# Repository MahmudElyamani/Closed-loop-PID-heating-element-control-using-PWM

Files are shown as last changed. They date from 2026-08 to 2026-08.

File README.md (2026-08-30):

# Closed-Loop PID Polyimide Heater Controller

A compact 72×42 mm PCB that drives a polyimide (Kapton) film heater with closed-loop PID temperature control, selectable between three preset temperature stages via a single push button.

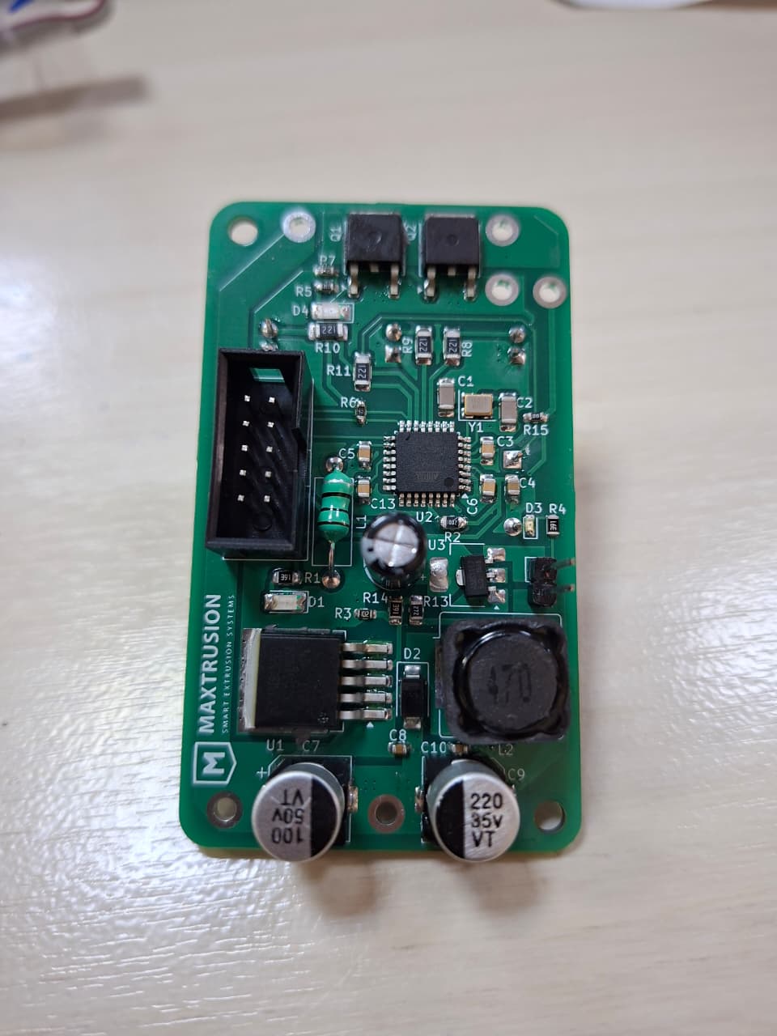
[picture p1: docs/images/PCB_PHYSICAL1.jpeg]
PCB Front

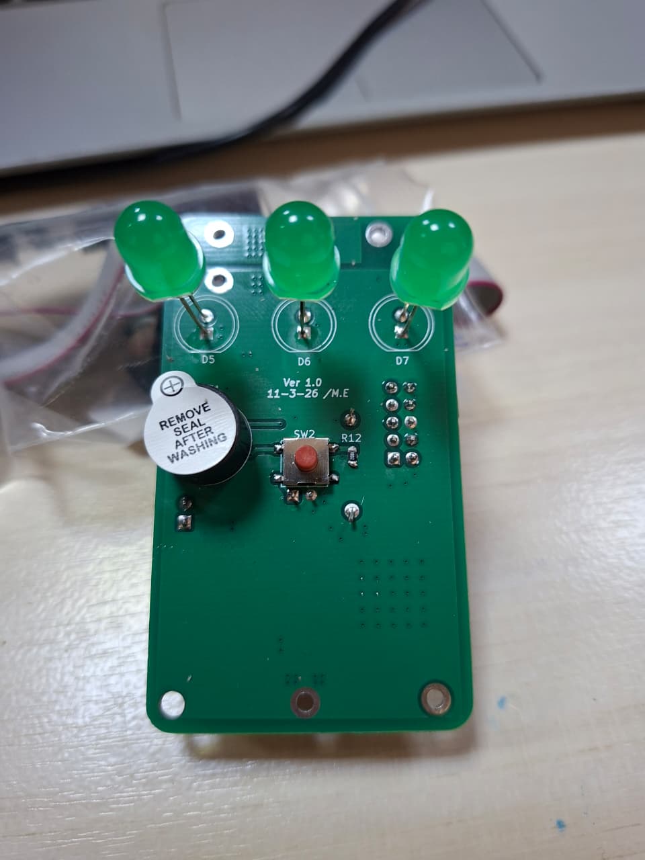
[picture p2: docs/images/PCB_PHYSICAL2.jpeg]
PCB Back


## Overview

This project was built to precisely and safely regulate the surface temperature of a polyimide heating element. Power switching is handled by a parallel dual-MOSFET stage driven by PWM from an ATmega328P, with temperature feedback provided by an NTC thermistor mounted on the heater. An onboard PID loop continuously adjusts duty cycle to track one of three user-selectable setpoints, with fault detection to shut everything down if the thermistor reading looks unsafe or the sensor is disconnected.

## Key Features

- **Closed-loop PID control** — thermistor feedback drives a PID loop that adjusts PWM duty cycle to hold the heater at the selected setpoint.
- **3 selectable temperature stages** (85 °C / 90 °C / 95 °C) — cycled with short button presses, each with its own status LED.
- **Press-and-hold start/stop** — holding the button for 2 seconds toggles the heater operation on or off, preventing accidental activation.
- **Fault protection** — the system continuously checks that the thermistor reading is within a safe, plausible range. If the reading looks unsafe (over-temperature or a disconnected/shorted sensor), the heater is disabled, a buzzer alert sounds, and the system latches into a fault state until conditions are safe again.
- **High-frequency PWM (~20 kHz)** — generated via direct Timer2 register configuration on the ATmega328P, above the audible range, for smoother MOSFET switching.
- **Averaged ADC sampling** — a rolling 500 ms window (100 samples at 5 ms spacing) smooths thermistor readings and rejects noise.
- **Audible feedback** — buzzer chirps on system start-up/ready and on operation stop.
- **Compact form factor** — entire control board fits on a 70×40 mm PCB.

## Hardware Summary

| Parameter | Value |
|---|---|
| Input power | 24 V, 5 A DC supply |
| Logic supply | Buck-regulated from 24 V rail down to 5 V for the ATmega328P |
| Power switching | 2× N-channel MOSFETs in parallel, PWM-gated |
| Microcontroller | ATmega328P (Arduino-compatible) |
| Temperature sensing | NTC thermistor (100 kΩ @ 25 °C, β ≈ 3950), voltage-divider with 100 kΩ series resistor |
| PWM frequency | ~20 kHz (Timer2, Fast PWM mode, prescaler 8, TOP = 99) |
| User interface | 1× push button, 3× status LEDs, 1× buzzer |
| Board size | 72 × 42 mm |

See [`hardware/README.md`](hardware/README.md) for schematic, PCB layout, and BOM details.

## How It Works

### Temperature sensing & safety check

The thermistor voltage is sampled every 5 ms and averaged over a rolling 500 ms window, then converted to °C using the Beta-parameter (simplified Steinhart-Hart) equation. Every loop iteration checks that:

- the computed temperature is below a danger threshold, **and**
- the raw ADC reading is below a value that would indicate a disconnected or shorted sensor.

If both checks pass, the system is marked safe and ready. If either fails, the system immediately disables the heater output, sounds the buzzer, and stays latched in a fault state until the reading recovers.

### Stage selection & control

Below is the operational flow, from power-up through fault handling:

```mermaid
flowchart TD
    A[Power On] --> B{Thermistor reading safe?}
    B -- No --> C[Fault state: heater off, buzzer alert]
    C --> B
    B -- Yes --> D[System Active / Ready]
    D --> E{Button held 2s?}
    E -- Yes --> F[Toggle Operation ON/OFF]
    F -->|OFF| D
    F -->|ON| G[Operation Active: PID control running]
    G --> H{Short button press?}
    H -- Yes --> I[Cycle Stage: 85C -> 90C -> 95C -> 85C]
    I --> G
    G --> B
```

Once operation is active, a PID loop (`Kp = 5.35, Ki = 0.5, Kd = 0.26`) computes a PWM duty cycle (0–80%) from the error between the current and target temperature, with integral anti-windup clamping. The corresponding status LED blinks while the heater is below its stage's threshold and turns solid once that threshold is reached.

See [`firmware/README.md`](firmware/README.md) for the full pin map and control-loop details.

## Repository Structure

```
heater-control-pcb/
├── README.md                 <- you are here
├── firmware/
│   ├── README.md             <- pin map, build/flash instructions, control logic
│   └── src/
│       └── main.cpp
├── hardware/
│   ├── README.md             <- PCB/schematic details, BOM
│   ├── schematic/            <- schematic PDF / source files
│   ├── pcb/                  <- PCB layout files, layer plots
│   ├── gerbers/              <- fabrication-ready Gerber/drill files
│   └── bom/                  <- bill of materials
└── docs/
    └── images/                <- board photos, renders, diagrams
```

## Getting Started

1. Clone the repository.
2. Fabricate the PCB using the files in [`hardware/gerbers`](hardware/gerbers).
3. Assemble per the BOM in [`hardware/bom`](hardware/bom).
4. Flash `firmware/src/main.cpp` to the ATmega328P — see [`firmware/README.md`](firmware/README.md) for details.
5. Connect a 24 V / 5 A supply and the polyimide heater + thermistor assembly.

## Gallery

| | | |
|---|---|---|
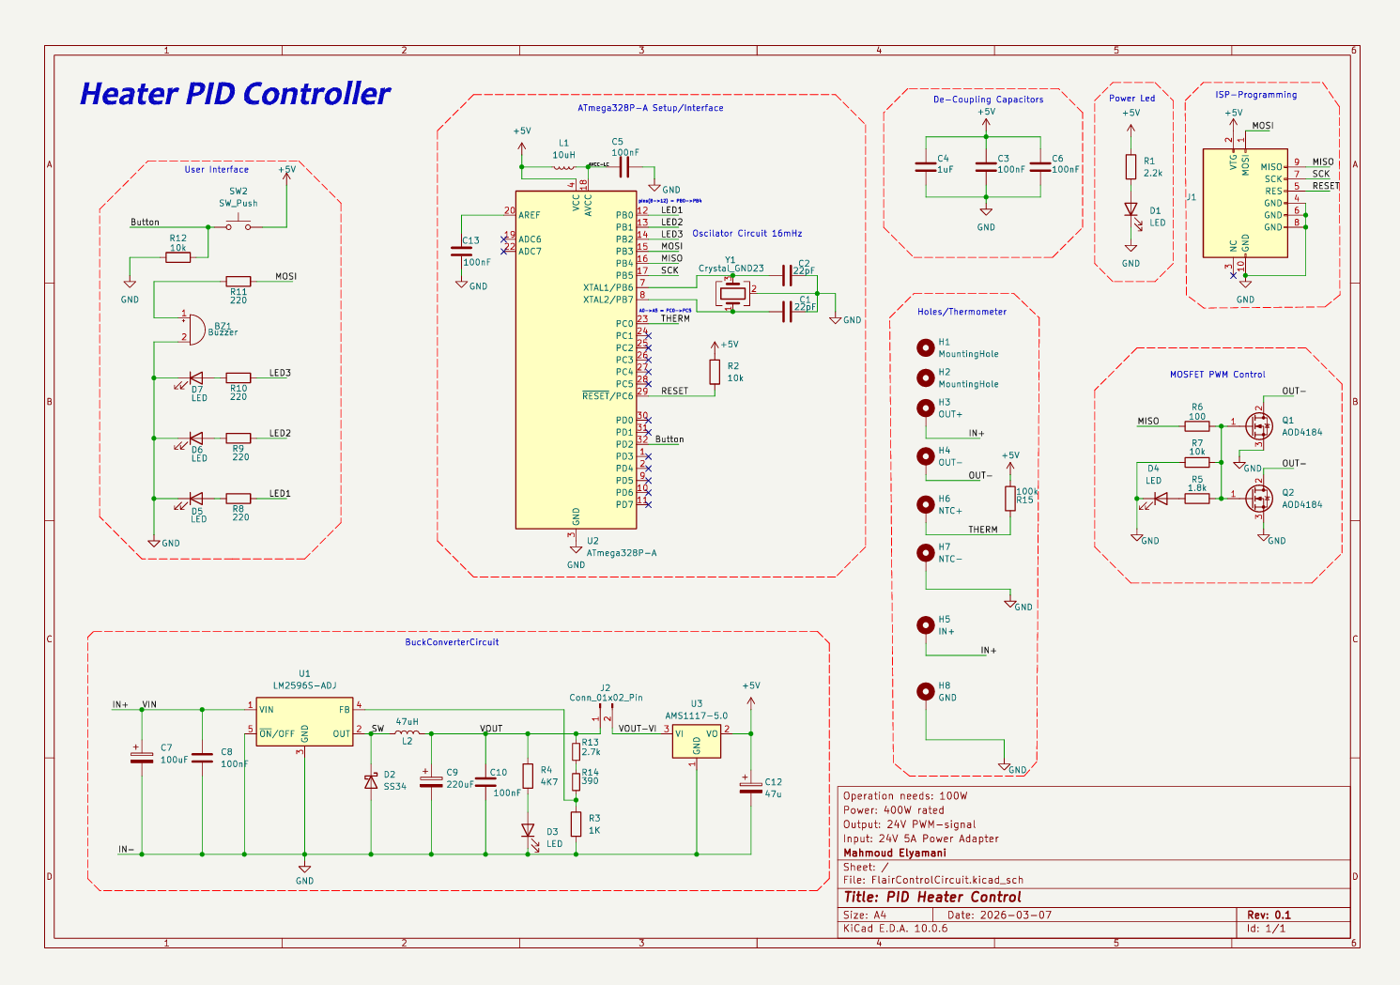
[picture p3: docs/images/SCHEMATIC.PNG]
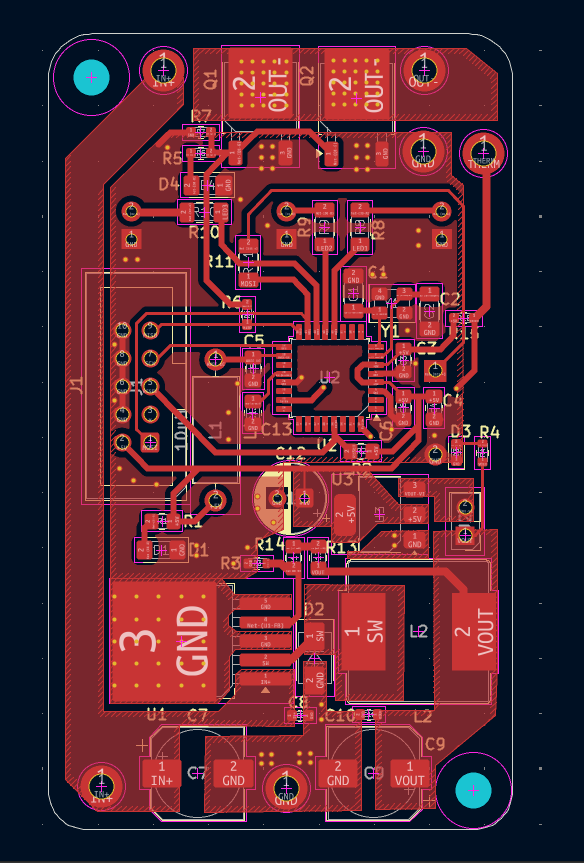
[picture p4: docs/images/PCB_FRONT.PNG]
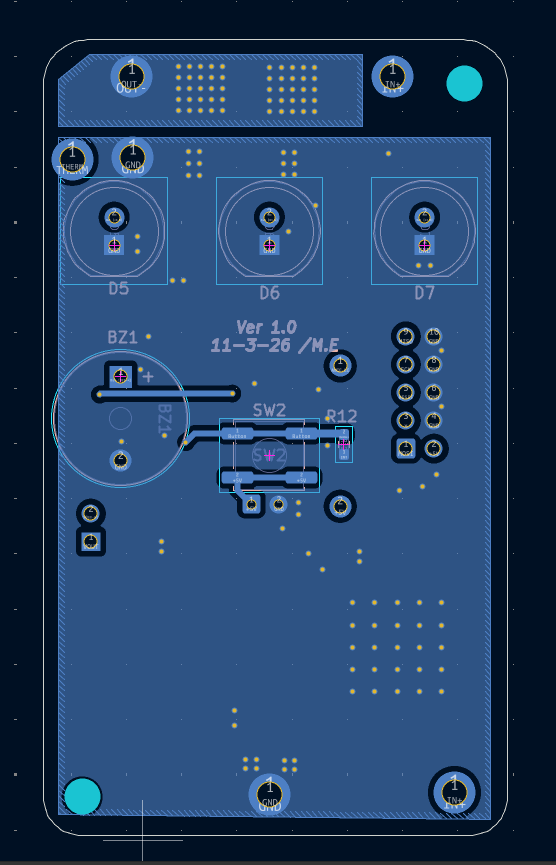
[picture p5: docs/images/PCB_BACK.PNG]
|  |  |  |

## Author

Built by Mahmoud Elyamani. Feel free to reach out with questions or suggestions.

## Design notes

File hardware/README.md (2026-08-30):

# Hardware

Schematic, PCB layout, and fabrication files for the heater controller board.

Schematic_Full
PCB_FRONT PCB_BACK

## Board Specs

| Parameter | Value |
|---|---|
| Dimensions | 70 × 40 mm |
| Input | 24 V DC, 4 A |
| Logic rail | 5 V, generated on-board via a buck regulator from the 24 V input |
| Power stage | 2× N-channel MOSFETs in parallel, PWM-driven from the MCU |
| MCU | ATmega328P |
| Sensing | NTC thermistor input (100 kΩ @ 25 °C, β ≈ 3950) via voltage divider |
| Outputs | Heater PWM (MOSFET gate), 3× LED, 1× buzzer |
| Input protection | *(document fuse/reverse-polarity/TVS protection here, if present)* |

## Power Architecture

```mermaid
flowchart LR
    PSU[24V 4A Supply] --> BUCK[Buck Regulator]
    BUCK --> MCU[ATmega328P]
    PSU --> MOSFETS["2x MOSFET (parallel)"]
    MCU -- PWM gate signal --> MOSFETS
    MOSFETS --> HEATER[Polyimide Heater]
    HEATER -- thermistor --> MCU
    MCU --> LEDS[3x Status LEDs]
    MCU --> BUZZER[Buzzer]
    BUTTON[Push Button] --> MCU
```

The 24 V rail feeds the MOSFET power stage directly and is stepped down separately for the microcontroller's 5 V logic supply, so heater switching noise is isolated from the control electronics as much as the layout allows.

## Why two parallel MOSFETs?

Splitting the switched current across two MOSFETs in parallel reduces the conduction losses (I²R) and thermal load per device compared to a single MOSFET rated for the full heater current, which helps keep both devices cooler on a compact 70×40 mm board with limited copper area for heatsinking.

## Directory Contents

- **`schematic/`** — schematic source file(s) and exported PDF.
- **`pcb/`** — PCB layout source file(s), layer plots / renders.
- **`gerbers/`** — fabrication-ready Gerber + drill files (zip per revision, e.g. `heater-controller-rev1-gerbers.zip`).
- **`bom/`** — bill of materials (CSV/XLSX), ideally with mouser/digikey/lcsc part numbers.

## Revision History

| Rev | Date | Notes |
|---|---|---|
| 1.0 | *(date)* | Initial release |

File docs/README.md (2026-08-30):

# Docs

Supporting media for the project.

- **`images/`** — board photos (top/bottom, assembled, in enclosure), heater in operation, any renders. Referenced from the root `README.md` gallery section.

Suggested shots to include, since this is going in a CV/portfolio:

1. Assembled PCB, top-down, well-lit, in focus (the "hero" shot).
2. PCB populated but before final assembly (shows soldering quality).
3. The heater + thermistor assembly connected to the board.
4. The board running, e.g. LED lit for an active stage.
5. A short clip or GIF of the button press → LED stage cycling → temperature rising (optional, but effective for a portfolio piece).
6. Any 3D render of the PCB from your CAD/EDA tool, if you have one — these often look cleaner than photos for a first impression.

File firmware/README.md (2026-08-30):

# Firmware

Arduino-framework firmware for the ATmega328P that runs the heater's safety monitoring, button/UI logic, and PID temperature control.

## Requirements

- Arduino IDE or PlatformIO
- Board: any ATmega328P target (e.g. "Arduino Uno" / "Arduino Nano" board definition, since this project uses the ATmega328P directly rather than a full Arduino module)
- No external libraries — only `Arduino.h`

## Pin Map

| Pin | Signal | Direction | Notes |
|---|---|---|---|
| D2 | Button | Input | Momentary push button |
| D3 | PWM_Pin | Output | Timer2 OC2B — MOSFET gate drive (~20 kHz) |
| D8 | LED1 | Output | Stage 1 (85 °C) indicator |
| D9 | LED2 | Output | Stage 2 (90 °C) indicator |
| D10 | LED3 | Output | Stage 3 (95 °C) indicator |
| D11 | Buzzer | Output | Audible alerts |
| A0 | THERM | Analog In | Thermistor voltage divider |

## Flashing

1. Open `src/main.cpp` in the Arduino IDE (rename to `.ino` or open as a sketch folder) or a PlatformIO project.
2. Select the correct board/programmer for your ATmega328P (ISP programmer if flashing a bare chip, or the appropriate serial port if using a bootloader).
3. Upload.
4. Optionally open the Serial Monitor at 9600 baud to view live duty cycle / current temperature / target temperature readings, useful for tuning.

## Control Logic

### 1. Temperature acquisition

`getAveragedReading()` maintains a circular buffer of 100 ADC samples (5 ms apart, 500 ms total window) and returns a running average, refreshed non-blockingly on every `loop()` call. The averaged ADC value is converted to resistance from the voltage divider, then to °C via the Beta-parameter equation:

```
1/T = 1/T0 + (1/B) * ln(R/R0)
```

with `R0 = 100 kΩ`, `T0 = 25 °C`, `B = 3950`.

### 2. Safety gating

A reading is considered safe if the computed temperature is below the current danger threshold **and** the raw ADC value is below 850 (guards against a disconnected/open thermistor, which reads as a near-maximum ADC value in this divider configuration). The danger threshold itself changes context: it's relaxed while running normally and tightened after a fault, so the system won't silently resume right at the edge of the fault condition.

### 3. Button handling

- **Held ≥ 2 s while the system is active:** toggles `operationActive` (heater run/stop). Stopping immediately zeroes duty cycle and target temperature and cycles the buzzer.
- **Short press/release (while operation is active):** advances `ButtonState` (0 → 1 → 2 → 0), selecting between the three temperature stages. Each stage sets its own `targetTemp` (85 / 90 / 95 °C) and drives its corresponding LED via `Blinktil()`, which blinks the LED until the stage's temperature threshold is reached, then holds it solid.

### 4. PID loop

`MePID()` runs a standard PID controller:

```
Kp = 5.35
Ki = 0.5
Kd = 0.26
```

- Integral term is clamped to ±80 to limit windup.
- Output (PWM duty cycle) is clamped to **0–80%**.
- `dt` is computed from `millis()` deltas each call.

The resulting duty percentage is written to the MOSFET gate via `pwmWrite_HF()`.

### 5. PWM generation

`pwmWrite_HF()` configures Timer2 directly (rather than using `analogWrite()`) for a higher, more consistent switching frequency than the default ~490 Hz/980 Hz Arduino PWM:

- Fast PWM, TOP = `OCR2A` (Mode 7)
- Prescaler = 8 → `f = 16 MHz / (8 × (1 + 99)) ≈ 20 kHz`
- Duty cycle written to `OCR2B` (non-inverting, `OC2B` / D3)

## Tuning Notes

The PID gains and the 0–80% output clamp are tuned for this specific heater's thermal mass and the 24 V/parallel-MOSFET power stage — if you build your own heater assembly with different thermal characteristics, re-tune `Kp`/`Ki`/`Kd` using the Serial Monitor output as feedback.

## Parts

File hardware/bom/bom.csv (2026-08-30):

Designator | Footprint | Quantity | Value | LCSC Part #
BZ1 | Buzzer_12x9.5RM7.6 | 1 | Buzzer
C1, C2 | 1206 | 2 | 22pF
C10, C8 | 0603 | 2 | 100nF
C12 | CP_Radial_D6.3mm_P2.50mm | 1 | 47u
C13, C3, C5, C6 | 0805 | 4 | 100nF
C4 | 0805 | 1 | 1uF
C7 | CP_Elec_8x10 | 1 | 100uF
C9 | CP_Elec_8x10 | 1 | 220uF
D1, D4 | 1206 | 2 | LED
D2 | D_SMA | 1 | SS34
D3 | 0603 | 1 | LED
D5, D6, D7 | LED_D8.0mm | 3 | LED
J1 | IDC-Header_2x05_P2.54mm_Vertical | 1 | Microsemi_FlashPro-JTAG-10
J2 | PinHeader_1x02_P2.54mm_Vertical | 1 | Conn_01x02_Pin
L1 | L_Axial_L9.5mm_D4.0mm_P12.70mm_Horizontal_Fastron_SMCC | 1 | 10uH
L2 | L_Bourns_SRR1208_12.7x12.7mm | 1 | 47uH
Q1, Q2 | TO-252-2 | 2 | AOD4184
R1 | 0805 | 1 | 2.2k
R10, R11, R8, R9 | 1206 | 4 | 220
R12, R7 | 0603 | 2 | 10k
R13 | 0805 | 1 | 2.7k
R14 | 0805 | 1 | 390
R15 | 0603 | 1 | 100k
R2 | 0805 | 1 | 10k
R3 | 0603 | 1 | 1K
R4 | 0603 | 1 | 4K7
R5 | 0603 | 1 | 1.8k
R6 | 0603 | 1 | 100
SW2 | SW_Push_1P1T_NO_CK_KSC7xxJ | 1 | SW_Push
U1 | TO-263-5_TabPin3 | 1 | LM2596S-ADJ
U2 | TQFP-32_7x7mm_P0.8mm | 1 | ATmega328P-A
U3 | SOT-223-3_TabPin2 | 1 | AMS1117-5.0
Y1 | Crystal_SMD_3225-4Pin_3.2x2.5mm | 1 | Crystal_GND23

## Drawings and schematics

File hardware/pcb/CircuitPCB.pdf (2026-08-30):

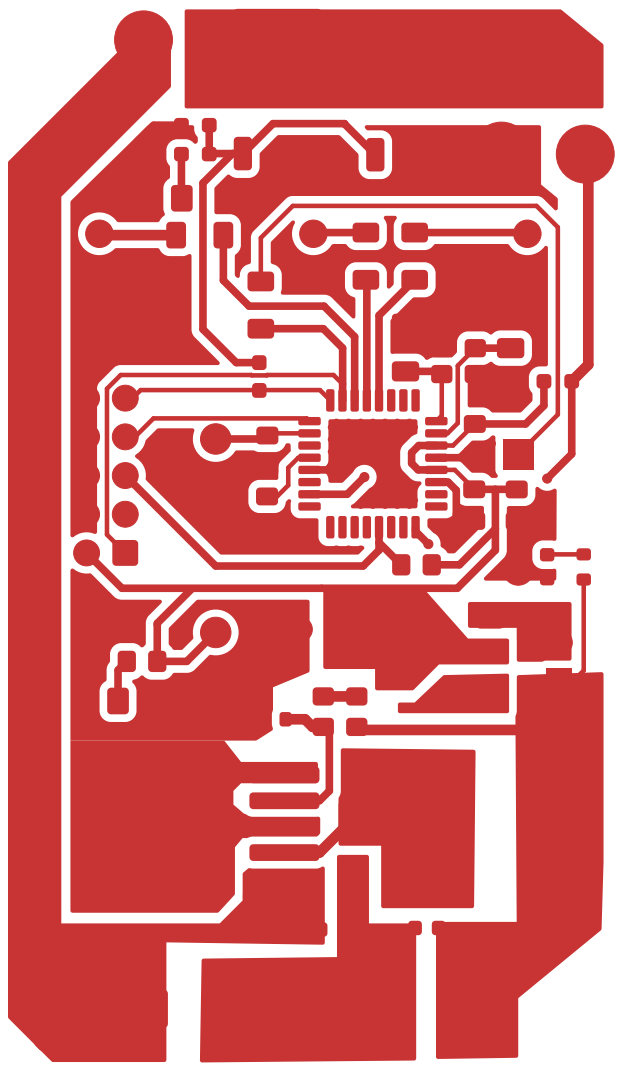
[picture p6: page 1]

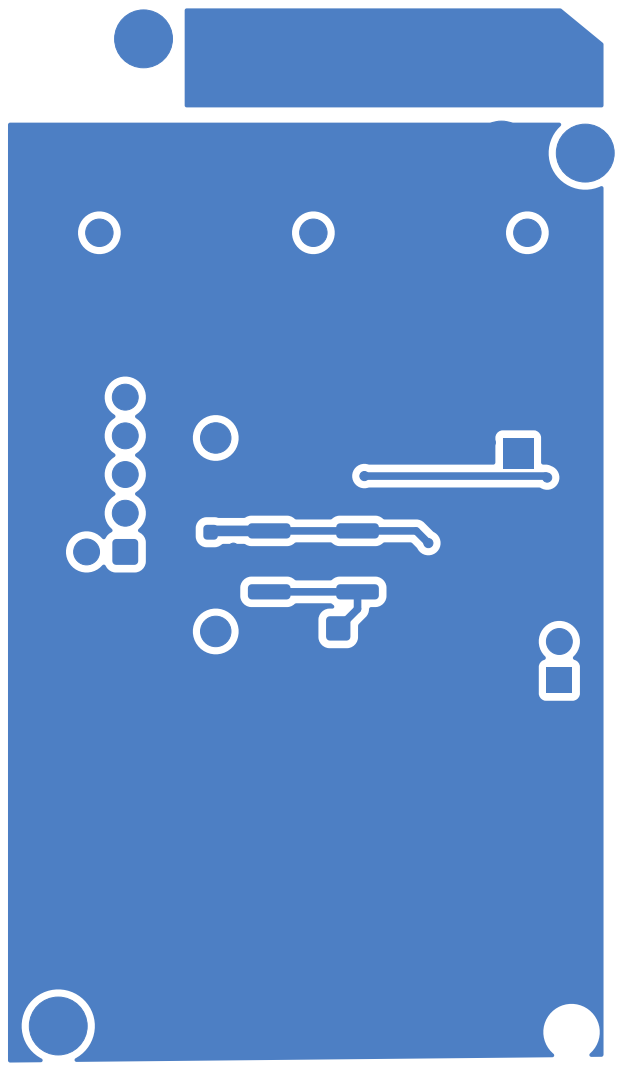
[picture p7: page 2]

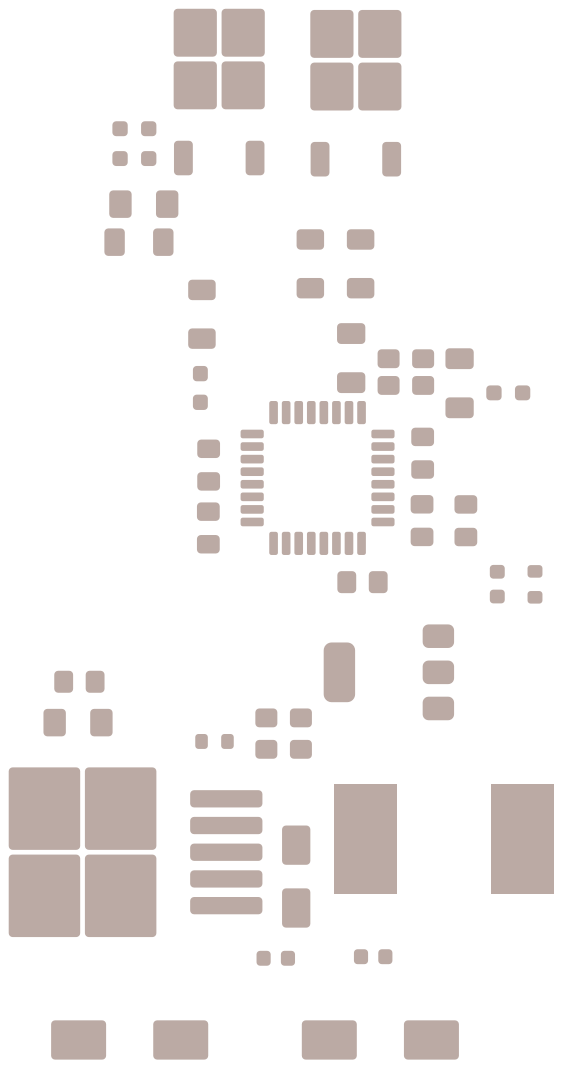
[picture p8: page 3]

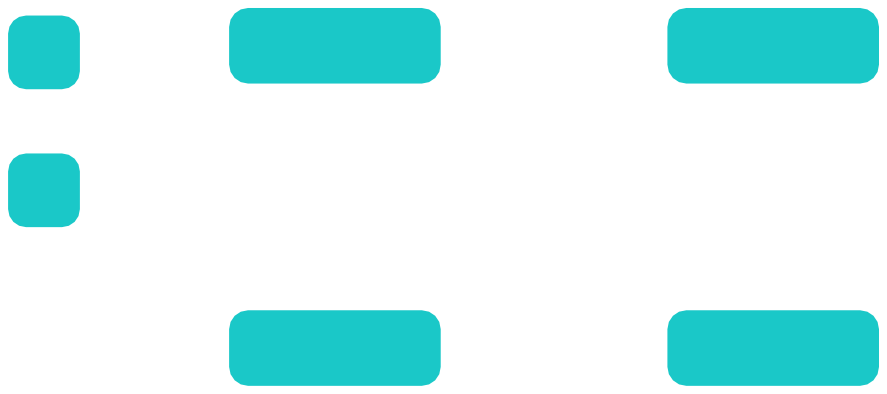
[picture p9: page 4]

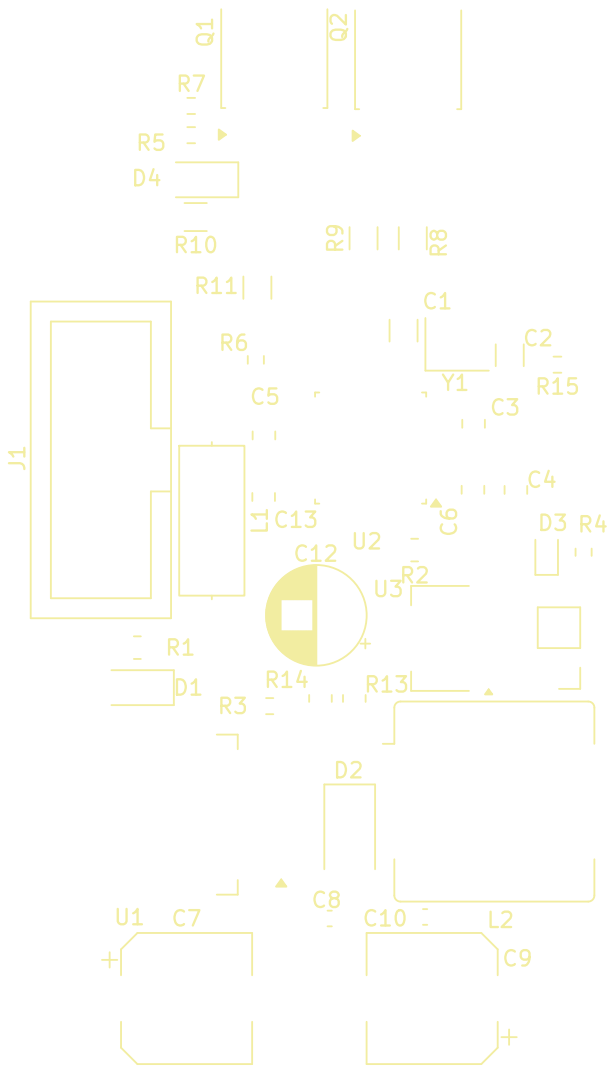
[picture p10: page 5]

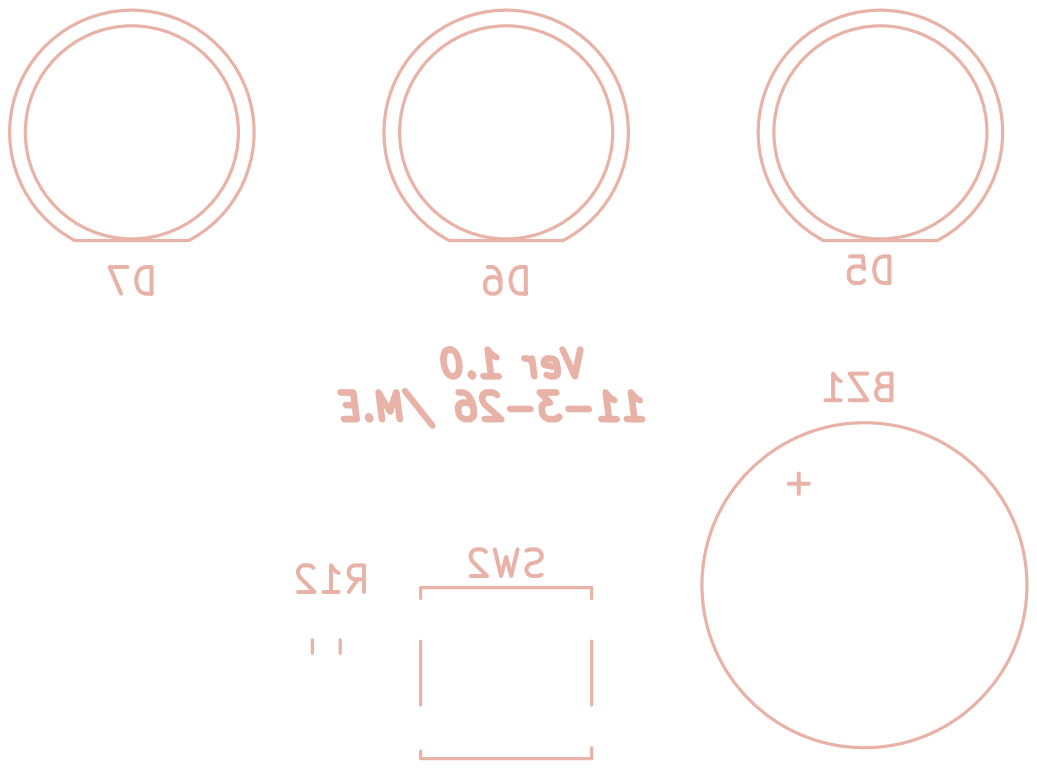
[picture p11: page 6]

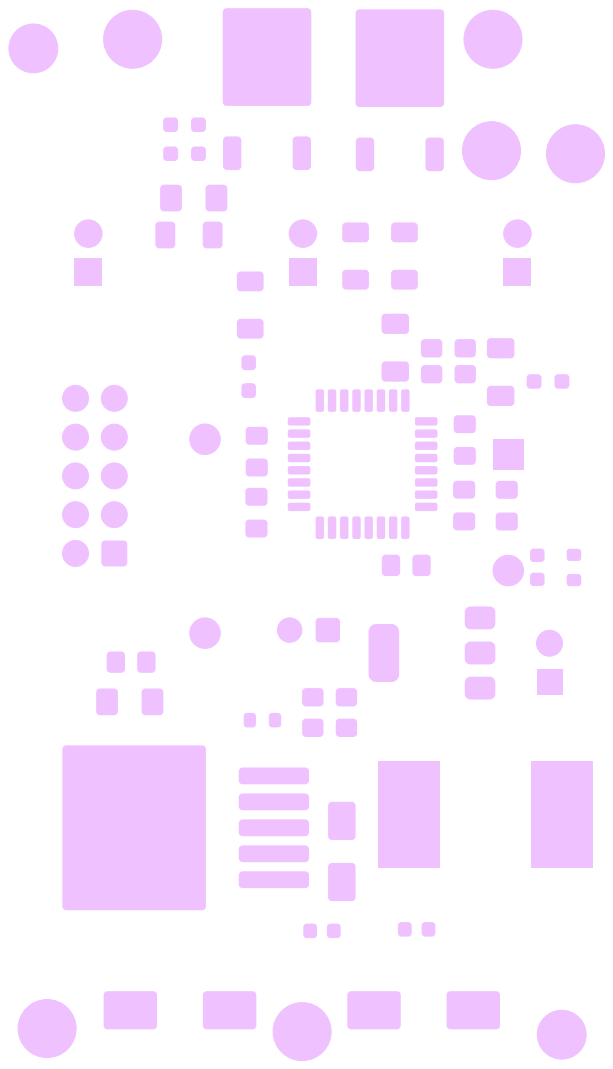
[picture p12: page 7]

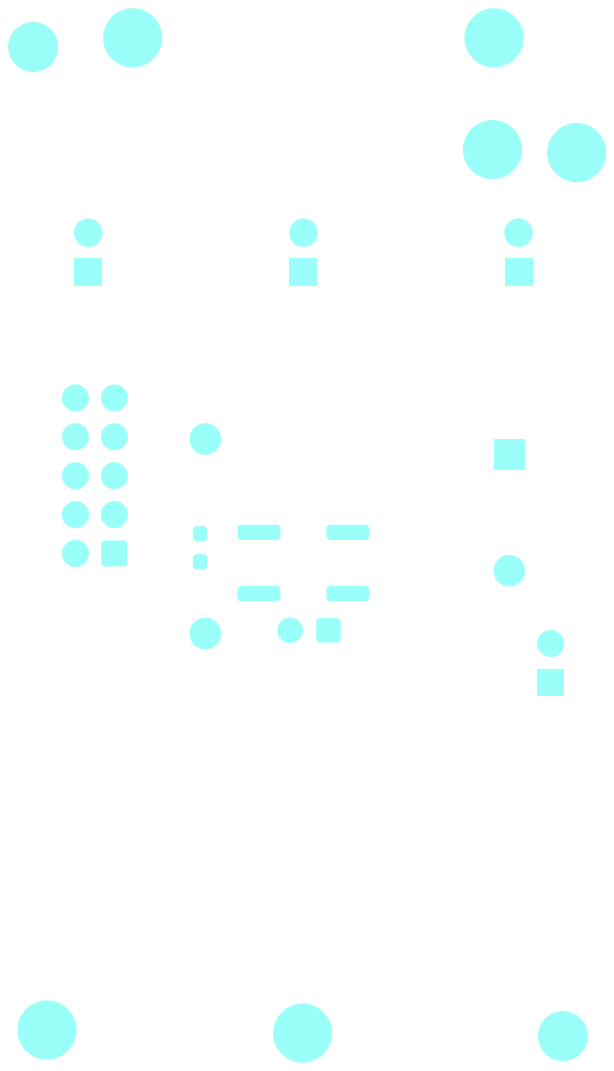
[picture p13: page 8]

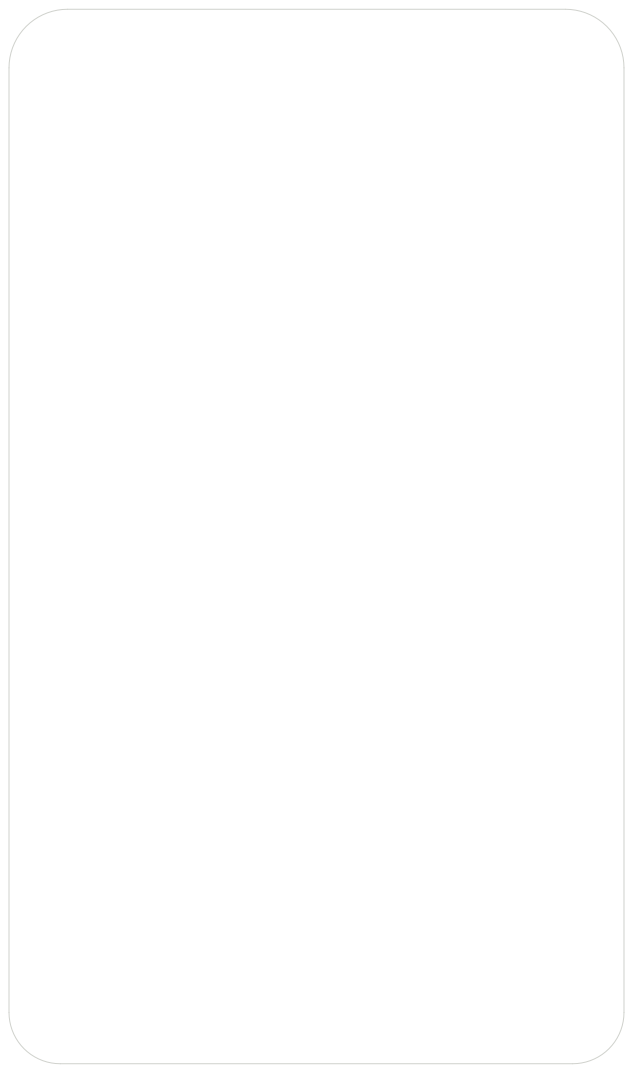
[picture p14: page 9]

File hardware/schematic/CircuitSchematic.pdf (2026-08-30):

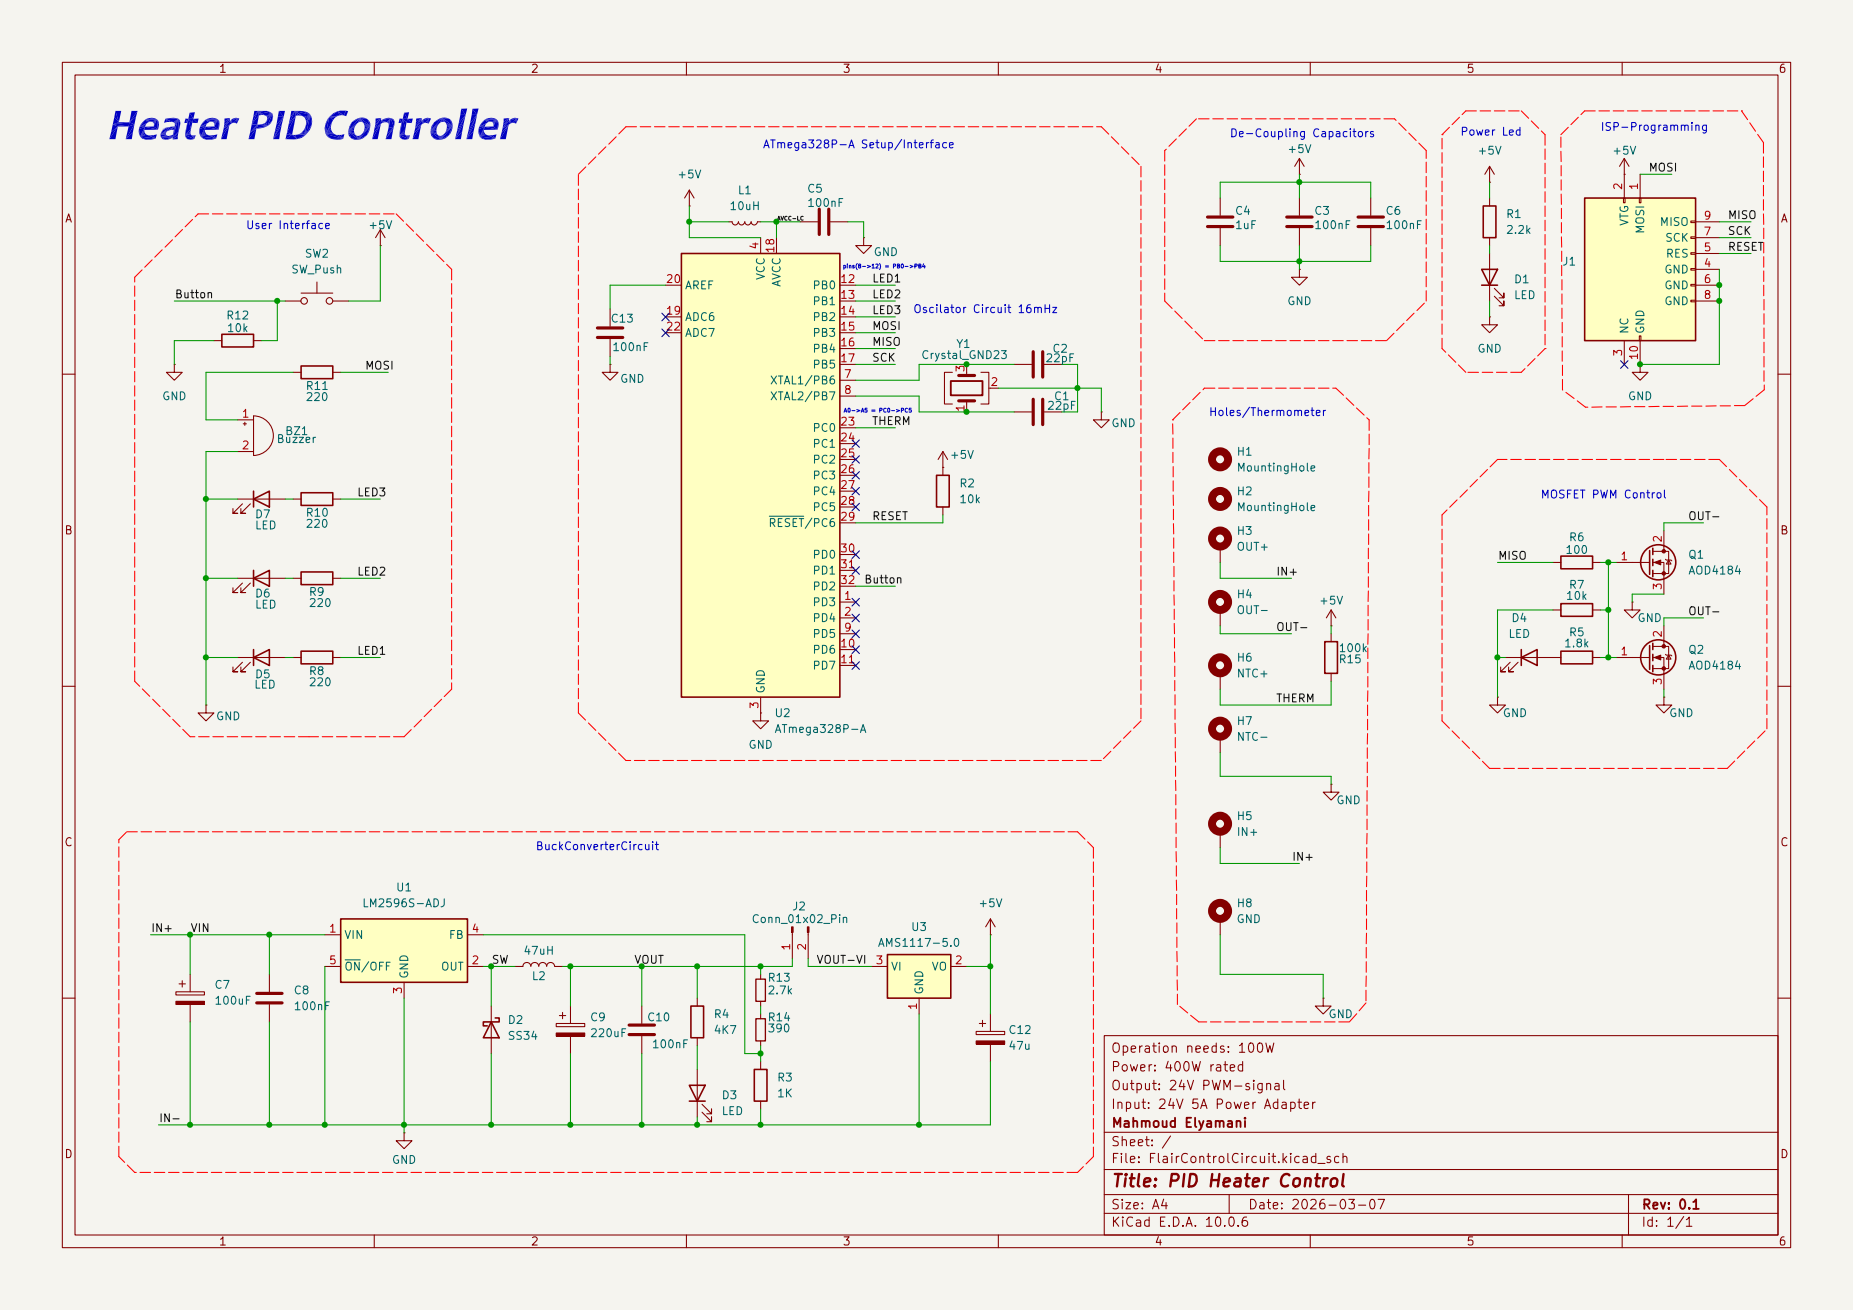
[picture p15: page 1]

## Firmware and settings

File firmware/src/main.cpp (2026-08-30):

#include <Arduino.h>

//Pin definitions:
#define BUTTON 2
#define LED1 8
#define LED2 9
#define LED3 10
#define Buzzer 11
#define PWM_Pin 3
bool systemActive = false;
bool operationActive = false;
bool faultTriggered = false;
unsigned long pressStartTime = 0;
bool buttonWasPressed = false;
bool actionTriggered = false;
short ButtonState = 0;

// Thermistor parameters
enum Temperatures
{
  Low = 83,          //465 = 21.03C,   923 = 85C
  Medium = 88,       //511 = 24.96C,   936 = 90C
  High = 93,         //546 = 28.07C,   947 = 95C
  Danger = 103       //567 = 30.09C,   1000 = ???
};
#define THERM A0
#define SERIES_RESISTOR 100000.0   // 100K resistor
#define NOMINAL_RESISTANCE 100000.0 // resistance at 25°C
#define NOMINAL_TEMPERATURE 25.0    // 25°C
#define BETA_COEFFICIENT 3950.0
int adcValue;
int rawADC;
int avg;
int DangerTemp = Danger;
const uint16_t SAMPLE_INTERVAL_MS = 5;   // sample every 5ms
const uint16_t WINDOW_TIME_MS = 500;     // total averaging window
const uint16_t NUM_SAMPLES = WINDOW_TIME_MS / SAMPLE_INTERVAL_MS;
uint16_t buffer[NUM_SAMPLES];
uint16_t index = 0;
uint32_t sum = 0;
unsigned long lastSampleTime = 0;

//PWM Parameters
static uint8_t pwm_top = 99;   // Default for ~20 kHz
static bool pwm_initialized = false;

//My PID Parameters
float duty;
float targetTemp;

//Function delarations:
void Blinktil(int,int,int);
void BuzzerStart();
void stopOperation();
void pwmWrite_HF(uint8_t);
float getAveragedReading();
void initAveraging();
float MePID(float, float);

void setup() 
{
  Serial.begin(9600);
  pinMode(BUTTON, INPUT);
  pinMode(LED1, OUTPUT);
  pinMode(LED2, OUTPUT);
  pinMode(LED3, OUTPUT);
  pinMode(Buzzer, OUTPUT);
  pinMode(PWM_Pin, OUTPUT);
  initAveraging();
}

void loop() 
{
  rawADC = getAveragedReading();
  adcValue = 1023 - rawADC;
  // Convert ADC value to resistance
  float voltage = adcValue / 1023.0;
  float resistance = SERIES_RESISTOR * (1.0 / voltage - 1.0);   //for reverse reading: float resistance = SERIES_RESISTOR * (voltage / (1.0 - voltage));
  // Apply Beta formula
  float steinhart;
  steinhart = resistance / NOMINAL_RESISTANCE;     // (R/R0)
  steinhart = log(steinhart);                      // ln(R/R0)
  steinhart /= BETA_COEFFICIENT;                   // 1/B * ln(...)
  steinhart += 1.0 / (NOMINAL_TEMPERATURE + 273.15); // + (1/T0)
  steinhart = 1.0 / steinhart;                     // Invert
  steinhart -= 273.15;                             // Convert to °C
  bool SafeTemp = (steinhart<DangerTemp && rawADC < 850);
  bool buttonPressed = digitalRead(BUTTON);

  //Temperature value printing:
  Serial.print("PWMDuty: ");
  Serial.print(duty);
  Serial.print(" | CurrentTemp: ");
  Serial.print(steinhart);
  Serial.print(" °C");
  Serial.print(" | TargetTemp: ");
  Serial.print(targetTemp);
  Serial.println(" °C");

  //Checks if thermistor is connected or if temperature is not above expected.
  if (SafeTemp && !systemActive)
  {
    systemActive = true;
    DangerTemp = Danger;
    faultTriggered = false;
    BuzzerStart();
  }
  if (!SafeTemp && !faultTriggered)
  {
    faultTriggered = true;
    systemActive = false;
    DangerTemp = Medium;
    stopOperation();
  }

  //Operation Mode (Waits for button to be held for 3s first)
  if(systemActive)
  {
        // Button just pressed
    if (buttonPressed && !buttonWasPressed)
    {
        pressStartTime = millis();
        actionTriggered = false;
    }
    // Button is being held
    if (buttonPressed && !actionTriggered)
    {
        if (millis() - pressStartTime >= 2000)
        {
            operationActive = !operationActive;  // toggle ON/OFF
            if (!operationActive)
              stopOperation();

            actionTriggered = true;             // prevent retrigger while holding
        }
    }

        if (!buttonPressed && buttonWasPressed)
    {
        if (!actionTriggered && operationActive)
        {
            ButtonState++;
            if (ButtonState >= 3)
            {
              ButtonState = 0;
              digitalWrite(LED2, LOW);
              digitalWrite(LED3, LOW);
            }
        }
    }
    buttonWasPressed = buttonPressed;
  }

  if (operationActive)
  {
    duty = MePID(steinhart, targetTemp); //PID Control 
    pwmWrite_HF((uint8_t)duty);
    if (ButtonState == 0)
    {
      targetTemp = 85.00;
      Blinktil(LED1, Low, steinhart);
    }
    if (ButtonState == 1)
    {
      targetTemp = 90.00;
      digitalWrite(LED1, HIGH);
      Blinktil(LED2, Medium, steinhart);
    }
    if (ButtonState == 2)
    {
      targetTemp = 95.00;
      digitalWrite(LED2, HIGH);
      Blinktil(LED3, High, steinhart);
    }
  }
}

void Blinktil(int LedNum, int Templimit, int tempRead)
{
  static unsigned long lastToggle[14]; // enough for all pins
  static bool ledState[14];

  if (tempRead < Templimit)
  {
    if (millis() - lastToggle[LedNum] >= 1000)
    {
      ledState[LedNum] = !ledState[LedNum];
      digitalWrite(LedNum, ledState[LedNum]);
      lastToggle[LedNum] = millis();
    }
  }
  else
  {
    digitalWrite(LedNum, HIGH);
  }
}

void BuzzerStart()
{
   digitalWrite(Buzzer, HIGH);
   delay(300);
   digitalWrite(Buzzer, LOW);
   delay(300);
}

void stopOperation()
{
  operationActive = false;
  ButtonState = 0;
  duty = 0;
  targetTemp = 0;
  pwmWrite_HF(0);
  digitalWrite(LED1, LOW);
  digitalWrite(LED2, LOW);
  digitalWrite(LED3, LOW);
    for (int i = 0; i<3; i++)
  {
    digitalWrite(Buzzer, HIGH);
    delay(100);
    digitalWrite(Buzzer, LOW);
    delay(30);
  }
}

void pwmWrite_HF(uint8_t dutyPercent) {
  if (!pwm_initialized) {
    pinMode(PWM_Pin, OUTPUT);

    // Stop Timer2
    TCCR2A = 0;
    TCCR2B = 0;

    // Fast PWM, Mode 7 (TOP = OCR2A)
    TCCR2A |= (1 << WGM20) | (1 << WGM21);
    TCCR2B |= (1 << WGM22);

    // Non-inverting mode on OC2B (Pin 3)
    TCCR2A |= (1 << COM2B1);

    // No prescaler
    TCCR2B |= (1 << CS20);

    // Set TOP for ~20 kHz
    // f = 16MHz / (1 * (1 + TOP)) → TOP = 799 for 20kHz
    // BUT Timer2 is 8-bit → max TOP = 255
    // So we approximate:
    // TOP = 99 → ~16MHz / 100 = 160 kHz (too high)
    // We must use prescaler

    // Use prescaler = 8:
    // f = 16MHz / (8 * (1 + TOP))
    // For 20kHz → TOP ≈ 99

    TCCR2B = (1 << WGM22) | (1 << CS21); // prescaler = 8

    pwm_top = 99;
    OCR2A = pwm_top;

    pwm_initialized = true;
  }

  // Clamp input
  if (dutyPercent > 100) dutyPercent = 100;

  // Convert % to compare value
  OCR2B = (pwm_top * dutyPercent) / 100;
}

float getAveragedReading() {
  unsigned long now = millis();

  if (now - lastSampleTime >= SAMPLE_INTERVAL_MS) {
    lastSampleTime = now;

    uint16_t newValue = analogRead(THERM);

    // Remove old value from sum
    sum -= buffer[index];

    // Add new value
    buffer[index] = newValue;
    sum += newValue;

    // Move index
    index++;
    if (index >= NUM_SAMPLES) index = 0;
  }

  // Return current average anytime
  return (float)sum / NUM_SAMPLES;
}

void initAveraging() 
{
  sum = 0;

  for (unsigned int i = 0; i < NUM_SAMPLES; i++) {
    uint16_t val = analogRead(THERM);
    buffer[i] = val;
    sum += val;
    delay(5); // small spacing between samples
  }
}

float MePID(float currentTemp, float targetTemp) {
  static float integral = 0;
  static float lastError = 0;
  static unsigned long lastTime = 0;

  float Kp = 5.35;  //1.93
  float Ki = 0.5;  //0.49
  float Kd = 0.26;  //0.35 most stable 

  unsigned long now = millis();
  float dt = (now - lastTime) / 1000.0;
  if (dt <= 0) dt = 0.001;

  float error = targetTemp - currentTemp;

  // --- Optional: fast heat-up ---
  // if (currentTemp < targetTemp - 10) {
  //  return 65;  // max allowed duty
  //}

  // --- PID ---
  integral += error * dt;

  // Anti-windup (important since output is capped at 50%)
  if (integral > 80) integral = 80;
  if (integral < -80) integral = -80;

  float derivative = (error - lastError) / dt;

  float output = Kp * error + Ki * integral + Kd * derivative;

  lastError = error;
  lastTime = now;

  // Clamp to 0–50% ONLY
  if (output > 80) output = 80;
  if (output < 0) output = 0;

  return output;
}

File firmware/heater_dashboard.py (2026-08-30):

import sys
import time
import serial
import serial.tools.list_ports
from collections import deque

from PyQt6.QtWidgets import (
    QApplication,
    QWidget,
    QVBoxLayout,
    QLabel,
    QGridLayout,
    QMessageBox
)

from PyQt6.QtCore import Qt, QTimer
from PyQt6.QtGui import QFont

import pyqtgraph as pg


# ============================================================
# SETTINGS
# ============================================================

BAUD_RATE = 115200
MAX_SAMPLES = 300

# Data format expected from Arduino:
#
# temperature,setpoint,heaterState
#
# Example:
# 84.2,85.0,1
#
# heaterState:
# 1 = ON
# 0 = OFF


# ============================================================
# AUTO SERIAL DETECTION
# ============================================================

def find_arduino_port():

    ports = serial.tools.list_ports.comports()

    for port in ports:

        description = port.description.lower()

        keywords = [
            "arduino",
            "ch340",
            "cp210",
            "usb serial",
            "stm",
            "cdc"
        ]

        if any(keyword in description for keyword in keywords):
            return port.device

    return None


# ============================================================
# MAIN WINDOW
# ============================================================

class HeaterDashboard(QWidget):

    def __init__(self):

        super().__init__()

        self.serialPort = None

        self.init_ui()

        self.connect_serial()

        self.init_timer()

    # ========================================================
    # UI
    # ========================================================

    def init_ui(self):

        self.setWindowTitle("Heater Controller Dashboard")

        self.setGeometry(100, 100, 1400, 800)

        self.setStyleSheet("""

            QWidget {
                background-color: #1e1e1e;
                color: white;
            }

            QLabel {
                color: white;
            }

        """)

        mainLayout = QVBoxLayout()

        self.setLayout(mainLayout)

        # ====================================================
        # TOP PANEL
        # ====================================================

        topGrid = QGridLayout()

        # Current Temperature
        self.tempLabel = QLabel("--.- °C")
        self.tempLabel.setAlignment(Qt.AlignmentFlag.AlignCenter)
        self.tempLabel.setFont(QFont("Arial", 42, QFont.Weight.Bold))

        # Setpoint
        self.setpointLabel = QLabel("Setpoint: --.- °C")
        self.setpointLabel.setAlignment(Qt.AlignmentFlag.AlignCenter)
        self.setpointLabel.setFont(QFont("Arial", 24))

        # Heater State
        self.heaterLabel = QLabel("HEATER OFF")
        self.heaterLabel.setAlignment(Qt.AlignmentFlag.AlignCenter)
        self.heaterLabel.setFont(QFont("Arial", 28, QFont.Weight.Bold))

        # Serial Status
        self.serialStatusLabel = QLabel("Disconnected")
        self.serialStatusLabel.setAlignment(Qt.AlignmentFlag.AlignCenter)
        self.serialStatusLabel.setFont(QFont("Arial", 18))

        topGrid.addWidget(self.tempLabel, 0, 0)
        topGrid.addWidget(self.setpointLabel, 0, 1)
        topGrid.addWidget(self.heaterLabel, 0, 2)
        topGrid.addWidget(self.serialStatusLabel, 1, 0, 1, 3)

        mainLayout.addLayout(topGrid)

        # ====================================================
        # GRAPH
        # ====================================================

        self.graphWidget = pg.PlotWidget()

        mainLayout.addWidget(self.graphWidget)

        self.graphWidget.setBackground("#1e1e1e")

        self.graphWidget.showGrid(x=True, y=True)

        self.graphWidget.setTitle(
            "Temperature vs Time",
            color="white",
            size="20pt"
        )

        styles = {
            "color": "white",
            "font-size": "14px"
        }

        self.graphWidget.setLabel(
            "left",
            "Temperature (°C)",
            **styles
        )

        self.graphWidget.setLabel(
            "bottom",
            "Samples",
            **styles
        )

        self.graphWidget.addLegend()

        # ====================================================
        # DATA BUFFERS
        # ====================================================

        self.xData = deque(maxlen=MAX_SAMPLES)

        self.tempData = deque(maxlen=MAX_SAMPLES)

        self.setpointData = deque(maxlen=MAX_SAMPLES)

        self.sampleNumber = 0

        # ====================================================
        # PLOT LINES
        # ====================================================

        self.tempLine = self.graphWidget.plot(
            pen=pg.mkPen(width=3),
            name="Temperature"
        )

        self.setpointLine = self.graphWidget.plot(
            pen=pg.mkPen(
                style=Qt.PenStyle.DashLine,
                width=2
            ),
            name="Setpoint"
        )

        # ====================================================
        # CSV LOGGING
        # ====================================================

        timestamp = time.strftime("%Y%m%d_%H%M%S")

        self.logFile = open(
            f"temperature_log_{timestamp}.csv",
            "w"
        )

        self.logFile.write(
            "Sample,Temperature,Setpoint,Heater\n"
        )

    # ========================================================
    # SERIAL CONNECTION
    # ========================================================

    def connect_serial(self):

        try:

            port = find_arduino_port()

            if port is None:

                self.serialStatusLabel.setText(
                    "Arduino Not Detected"
                )

                self.serialStatusLabel.setStyleSheet(
                    "color: red;"
                )

                return

            self.serialPort = serial.Serial(
                port,
                BAUD_RATE,
                timeout=1
            )

            time.sleep(2)

            self.serialStatusLabel.setText(
                f"Connected: {port}"
            )

            self.serialStatusLabel.setStyleSheet(
                "color: lime;"
            )

            print(f"Connected to {port}")

        except Exception as e:

            print(e)

            self.serialStatusLabel.setText(
                "Connection Failed"
            )

            self.serialStatusLabel.setStyleSheet(
                "color: red;"
            )

    # ========================================================
    # TIMER
    # ========================================================

    def init_timer(self):

        self.timer = QTimer()

        self.timer.timeout.connect(
            self.update_data
        )

        self.timer.start(50)
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

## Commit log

2026-08-30 Replace placeholder image with actual PCB photos
    Updated images in README to reflect actual PCB photos.
2026-08-30 Enhance README with schematic image and instructions
    Added schematic image to README and updated instructions.
2026-08-30 Add PCB images to hardware README
    Added images of the PCB front and back to the README.
2026-08-30 Update README to format PCB images
    Combine PCB front and back images into a single line.
2026-08-30 Revise PCB specs and author information in README
    Updated the PCB dimensions, input power specifications, and author name in the README.
